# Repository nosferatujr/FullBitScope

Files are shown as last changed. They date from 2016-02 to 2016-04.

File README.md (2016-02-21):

# FullBitScope
Power Controller and 3p Printed box for BitScope Raspberry Pi and Official Touch 7'' Display

full description in : http://nosfebloc.blogspot.com.es/

We plan also sell on line both the assembled pcb and the box, just in case you have difficulties on build yours, but first we need to buid the first working unit.

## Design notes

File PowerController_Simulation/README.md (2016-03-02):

Simulación para proteus
Hex file is only for test propose. For use on your prototipe use the one on the PowerController_PIC folder

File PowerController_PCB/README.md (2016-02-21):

Schematic and PCB created with http://www.cadsoftusa.com/download-eagle/freeware/

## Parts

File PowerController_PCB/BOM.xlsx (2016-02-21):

Part | Value | Device | Package | Description | MF | OC_FARNELL | OC_NEWARK
C1 | 100n | C-EUC0805 | C0805 | CAPACITOR, European symbol
IC1 | 12F629 | PIC12F629SN | SO-08 | Data Sheet 8-Pin FLASH-Based 8-Bit CMOS Microcontrollers | MICROCHIP | 9759000 | 61K3433
JP1 | USB-RECEPTABLE | USB-RECEPTABLE | FCI-10103594-0001LF | USB Receptable |  | 2293752(farnell) (http://es.farnell.com/jsp/search/productdetail.jsp?CMP=i-ddd7-00001003&sku=2293752)
Q1, Q2 | AP4435GH | IRFR5305 | D-PAK_TO252AA | HEXFET Power MOSFET
R1, R3, R4, R7 | 2k2 | R-EU_R0805 | R0805 | RESISTOR, European symbol
R2 | 330 OHMIOS | R-EU_R0805 | R0805 | RESISTOR, European symbol
R5, R6 | 4k7 | R-EU_R0805 | R0805 | RESISTOR, European symbol
S1 | RF15L2 | RF15L2 | RF15L2 | RAFI SWITCH
SV1 |  | MA05-1 | FE05-1 | PINES MACHO |  | unknown | unknown
SV2 |  | MA04-1 | MA04-1 | PINES MACHO ACODADO |  | unknown | unknown
X1, X2 | 22-23-2021 | MA02-1 | 22-23-2021 | PINES MACHO ACODADO | MOLEX | 1462926 | 25C3832
T1, T2, T3 | BC848 | BC848 | SOT23 | NPN TRANSISTOR

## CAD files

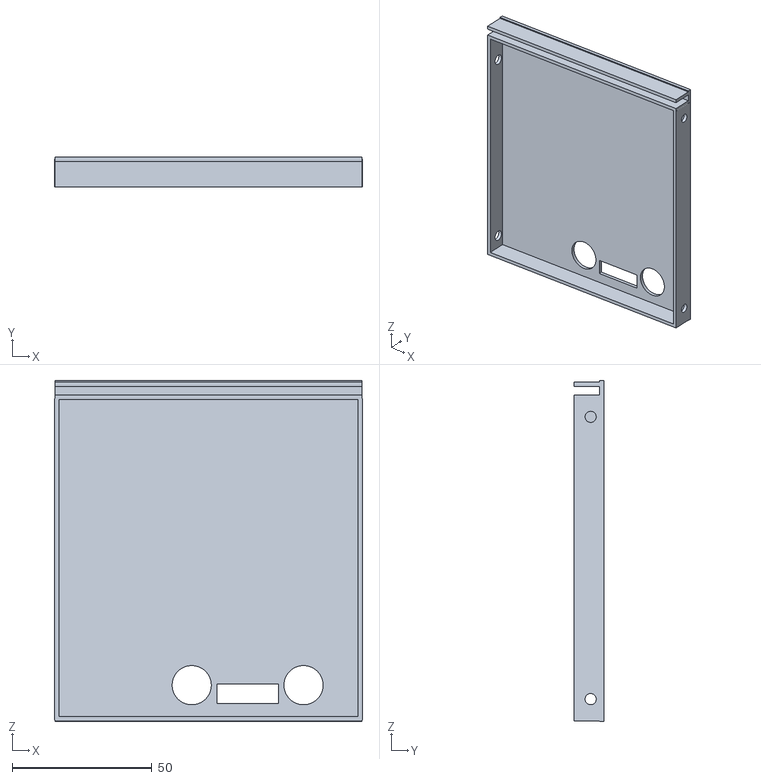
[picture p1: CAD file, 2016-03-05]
Box_STL_files/left.stl
110.2 x 10.8 x 122.0

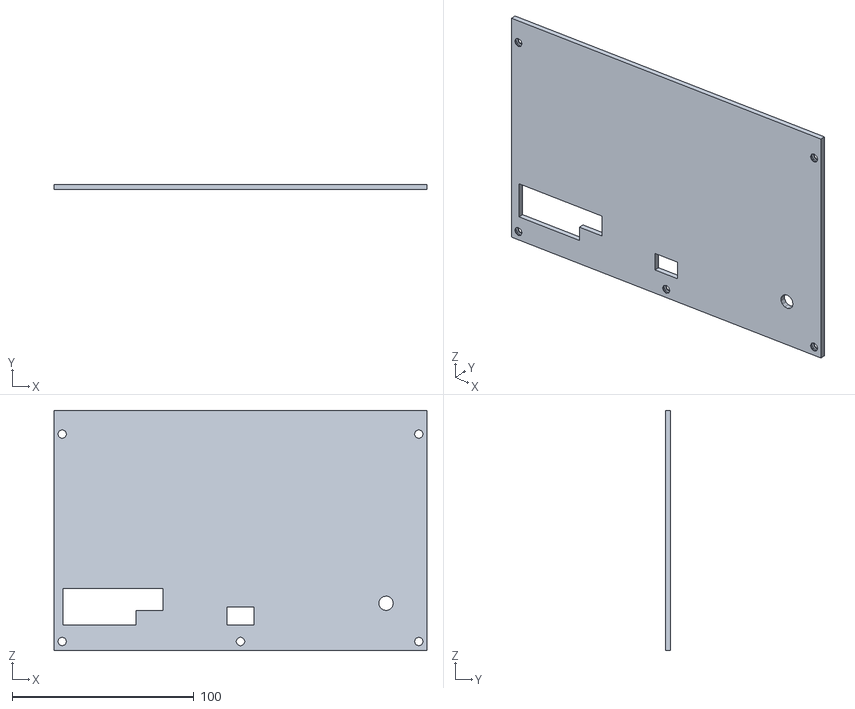
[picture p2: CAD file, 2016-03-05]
Box_STL_files/rear.stl
205.0 x 3.00 x 132.0

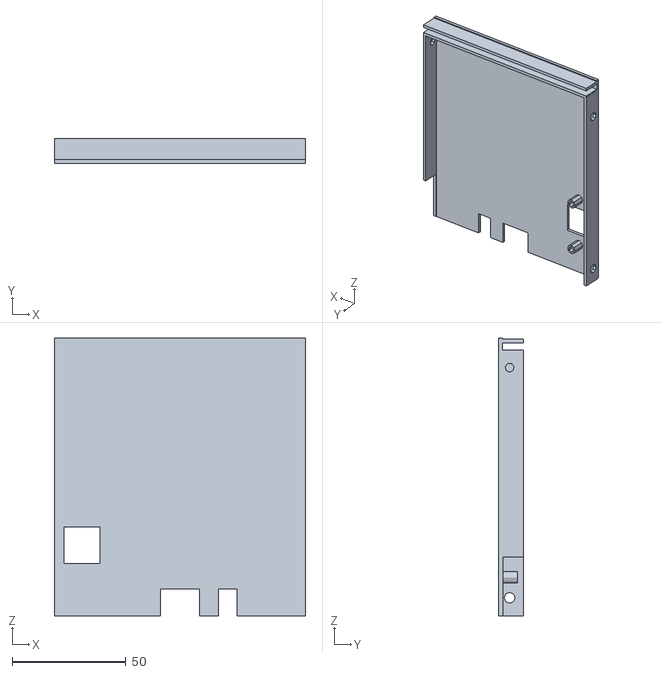
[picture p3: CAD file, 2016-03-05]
Box_STL_files/right.stl
110.2 x 10.8 x 122.0

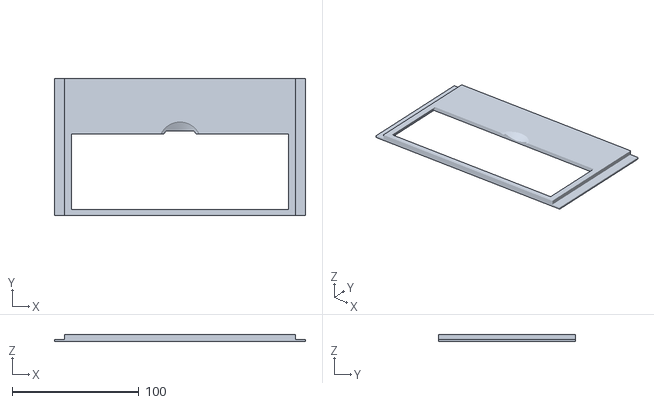
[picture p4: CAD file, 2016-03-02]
Box_STL_files/top1.stl
198.0 x 108.0 x 5.30

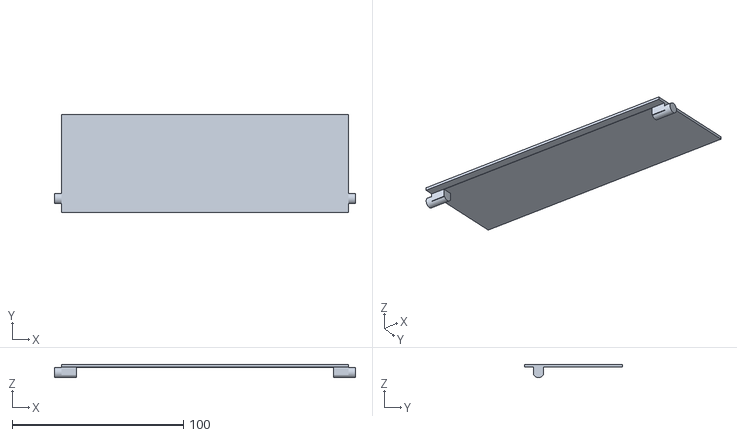
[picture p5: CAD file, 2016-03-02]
Box_STL_files/top3.stl
176.0 x 57.5 x 7.80

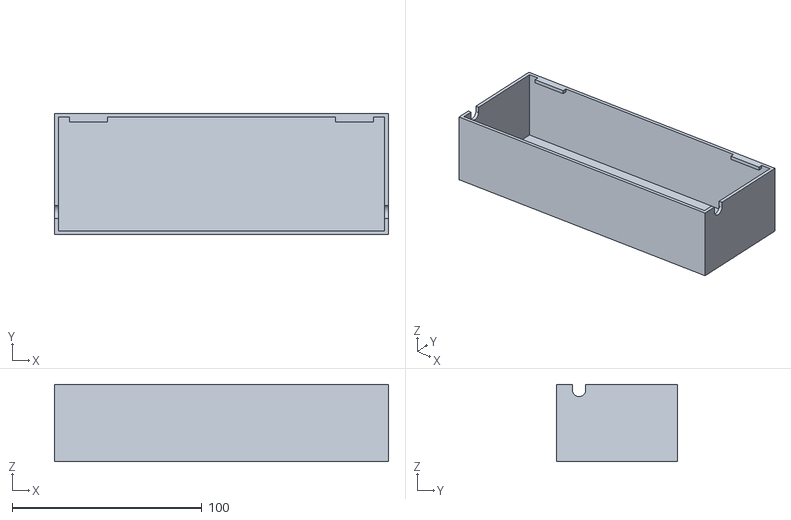
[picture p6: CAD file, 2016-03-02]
Box_STL_files/top2.stl
176.0 x 64.0 x 40.8

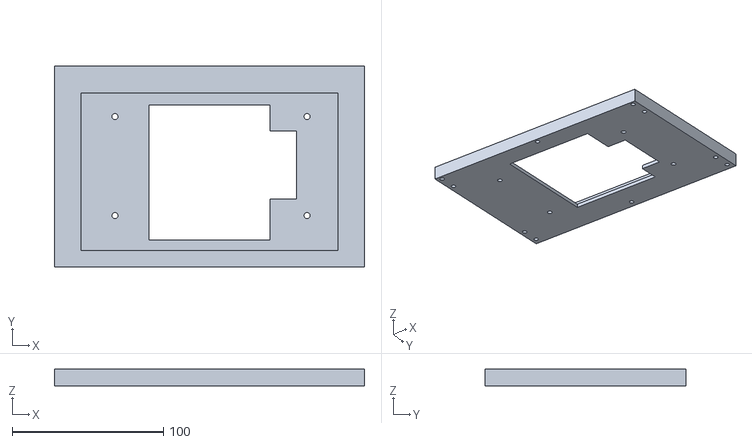
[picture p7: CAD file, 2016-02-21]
Box_STL_files/front.stl
205.0 x 132.9 x 11.0

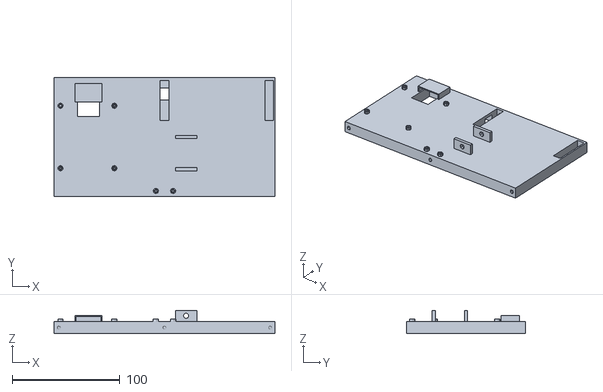
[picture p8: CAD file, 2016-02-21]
Box_STL_files/base.stl
205.0 x 110.0 x 21.5

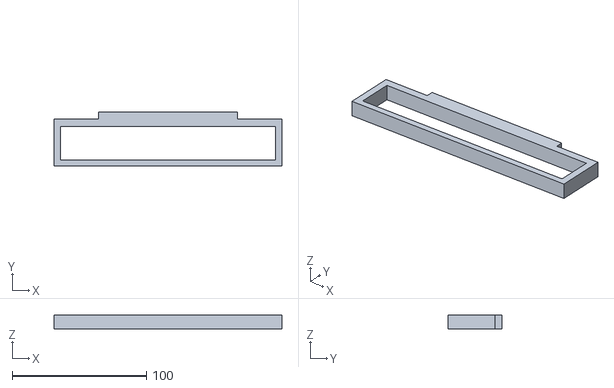
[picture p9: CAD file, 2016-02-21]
Box_STL_files/foot.stl
170.0 x 40.0 x 10.5

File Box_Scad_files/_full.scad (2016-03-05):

include <base.scad>
include <foot.scad>
include <front.scad>
include <top.scad>
include <right.scad>
include <left.scad>
include <rear.scad>

translate([0, -57, 61 ]) rear(); 

color("green")base();
  translate([0, 40, -21 ]) rotate([90, 0, 0 ])
foot();

  translate([0, 60.5, 59.5 ]) rotate([270, 180, 0 ])
front(); 

  translate([-102, 0, 66 ]) rotate([0, 0, 270 ])
color("red")right();

   translate([102, 0, 66 ]) rotate([0, 0, 270 ])
color("red")left();

translate([0, 0 , 125.5 ]) 
 top();

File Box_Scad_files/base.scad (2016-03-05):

module _screws_box(diam){
	translate([98, 0 , 2 ])  cylinder(  9 , 1,  diam/2 ,true);
	translate([0, 0 , 2 ])  cylinder(  9 , 1,  diam/2 ,true);
	translate([-98, 0 , 2 ])  cylinder(  9 , 1,  diam/2 ,true);
} 
 
module screws_box(){
	translate([0, -49, 0 ]) rotate([90, 0 , 0 ]) _screws_box(4);
	translate([0, 49, 0 ]) rotate([-90, 0 , 0 ]) _screws_box(4.5);
} 
module soporte_pi (){
	translate([25, 29, 5.5 ])  cylinder(  5 , 2.5,  2.5 ,true); 
	translate([-25, -29,  5.5 ])  cylinder(  5 , 2.5,  2.5 ,true); 
	translate([-25, 29,  5.5 ])  cylinder(  5 , 2.5,  2.5 ,true); 
	translate([25, -29,  5.5 ])  cylinder(  5 , 2.5,  2.5 ,true); 
}
 module talpwr(){
  translate([8, -50, 4.5 ])  cylinder(  9 , 1,  1.7 ,true);
  translate([-8, -50, 4.5 ])  cylinder(  9 , 1,  1.7 ,true);    
 }
 
 module tal_pi(){
 translate([25, 29, 4.5]) cylinder(  9 , 1,  1.7 ,true);
 translate([-25, -29,  4.5 ]) cylinder(  9 , 1,  1.7 ,true);
 translate([-25, 29,  4.5 ])cylinder(  9 , 1,  1.7 ,true);
 translate([25, -29,  4.5 ]) cylinder(  9 , 1,  1.7 ,true); 
 }

module sd(){
    difference(){
  cube([25 , 17,6 ] ,true ); 
   translate([0, -1,  -1 ])cube([23 , 17, 6 ] ,true );  
    } 
} 
 
module box(){ 
	difference(){
		difference(){
			cube([205 , 110,11 ] ,true ); 
			screws_box();
		}
		translate([(102.5-32)*-1, 33, 0 ])  cube([20 , 28, 12 ] ,true ); 
	}

	translate([-71.5, 0, 0 ]) soporte_pi();
	translate([8, -50, 5.5 ])  cylinder(  5 , 2.5,  2.5 ,true); 
	translate([-8, -50, 5.5 ])  cylinder(  5 , 2.5,  2.5 ,true);  
}
 
 module base(){
	difference(){
		box();
		translate([0, 40, -3 ])   cube([105 , 11,11 ] ,true ); 
		translate([0, -40, -3 ])   cube([105 , 11,11 ] ,true ); 
		translate([97, 34, 1.5 ])   cube([8, 37,9 ] ,true ); 
		translate([0, 34, 1.5 ])   cube([8, 37,9 ] ,true ); 
		translate([-99, 34, 0 ])   cube([8, 37,9 ] ,true ); 
		translate([-71.5, 0, 0 ]) tal_pi();
		talpwr();
	}
	difference(){ 
		union(){ 
			translate([20, 0, 10 ])   cube([20, 3, 12] ,true ); 
			translate([20, -30, 10 ])   cube([20, 3, 12] ,true ); 
		}
		translate([20, -10, 11 ]) rotate([90, 0 , 0 ]) cylinder(  60 , 2.5,  2.5 ,true); 
	}
	translate([-70.5, 41, 8.4 ]) sd();
}
//base();

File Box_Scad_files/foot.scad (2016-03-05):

module foot(){
difference(){
difference(){
translate([0, 0, 0 ])   cube([170 , 40,10.5 ] ,true );
difference(){    
translate([0, 18, 0 ])   cube([175 , 6,12 ] ,true );
translate([0, 18, 0 ])   cube([104 , 6,12 ] ,true );
}
}    
translate([0, -3, 0 ])   cube([160 , 25,12 ] ,true );
}
}

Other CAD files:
PowerController_PIC/production/pipower.X.production.obj
Box_Scad_files/front.scad
Box_Scad_files/left.scad
Box_Scad_files/rear.scad
Box_Scad_files/right.scad
Box_Scad_files/top.scad

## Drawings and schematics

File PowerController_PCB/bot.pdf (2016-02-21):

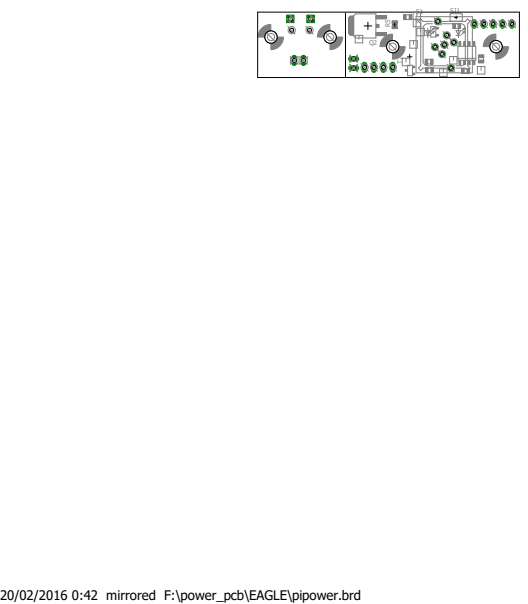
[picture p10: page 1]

20/02/2016 0:42 mirrored F:\power_pcb\EAGLE\pipower.brd

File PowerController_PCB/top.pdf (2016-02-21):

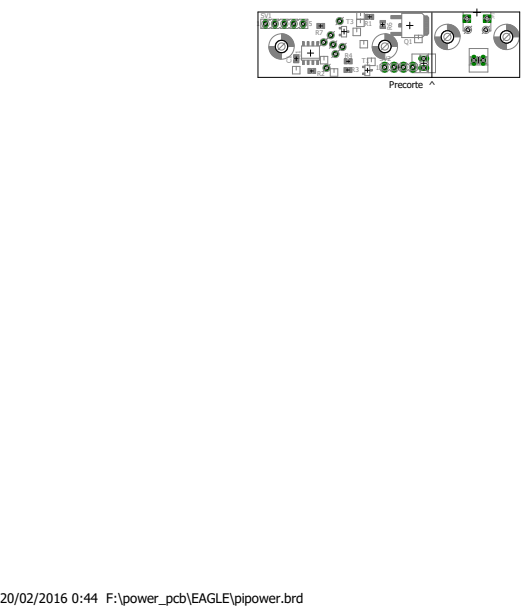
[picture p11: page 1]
JP1 Precorte ^

20/02/2016 0:44 F:\power_pcb\EAGLE\pipower.brd

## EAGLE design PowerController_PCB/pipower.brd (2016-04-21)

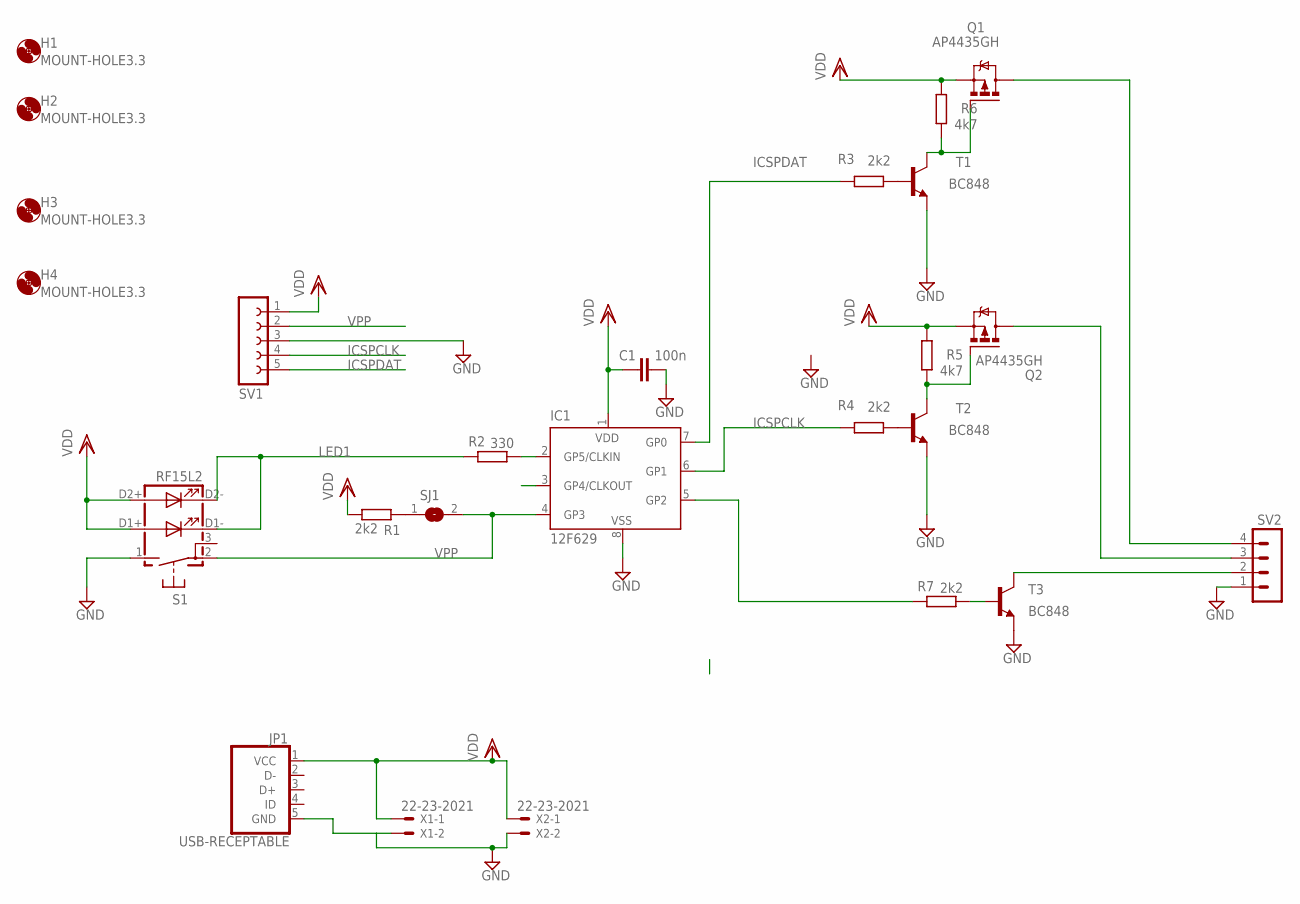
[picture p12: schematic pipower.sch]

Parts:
C1: 100n; C0805
H1, H2, H3, H4: MOUNT-HOLE3.3; 3,3
IC1: 12F629; SO-08; MPN PIC12F629-I/SN
JP1: USB-RECEPTABLE; FCI-10103594-0001LF
Q1, Q2: AP4435GH; D-PAK_TO252AA
R1, R3, R4, R7: 2k2; R0805
R2: 330; R0805
R5, R6: 4k7; R0805
S1: RF15L2
SJ1: SJ
SV1: FE05-1
SV2: MA04-1
T1, T2, T3: BC848; SOT23
X1, X2: 22-23-2021

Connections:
GND: C1.2, IC1.8 (VSS), JP1.5 (GND), S1.1 (S), SV1.3, SV2.1, T1.2 (E), T2.2 (E), T3.2 (E), X1.2, X2.2
ICSPCLK: IC1.6 (GP1), R4.2, SV1.4
ICSPDAT: IC1.7 (GP0), R3.2, SV1.5
LED1: R2.2, S1.D1- (C1), S1.D2- (C2)
unnamed: IC1.5 (GP2), R7.2
unnamed: Q1.4 (D), SV2.4
unnamed: Q2.1 (G), R5.1, T2.3 (C)
unnamed: R3.1, T1.1 (B)
unnamed: R1.2, SJ1.1
unnamed: R4.1, T2.1 (B)
unnamed: Q2.4 (D), SV2.3
unnamed: Q1.1 (G), R6.1, T1.3 (C)
unnamed: IC1.2 (GP5/CLKIN), R2.1
unnamed: SV2.2, T3.3 (C)
unnamed: R7.1, T3.1 (B)
VDD: C1.1, IC1.1 (VDD), JP1.1 (VCC), Q1.3 (S), Q2.3 (S), R1.1, R5.2, R6.2, S1.D1+ (A1), S1.D2+ (A2), SV1.1, X1.1, X2.1
VPP: IC1.4 (GP3), S1.2, SJ1.2, SV1.2

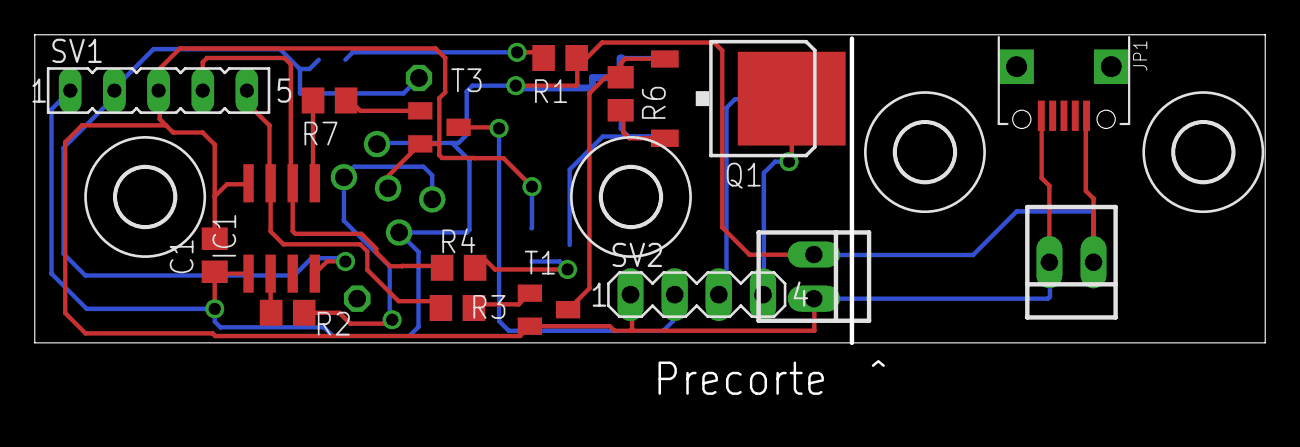
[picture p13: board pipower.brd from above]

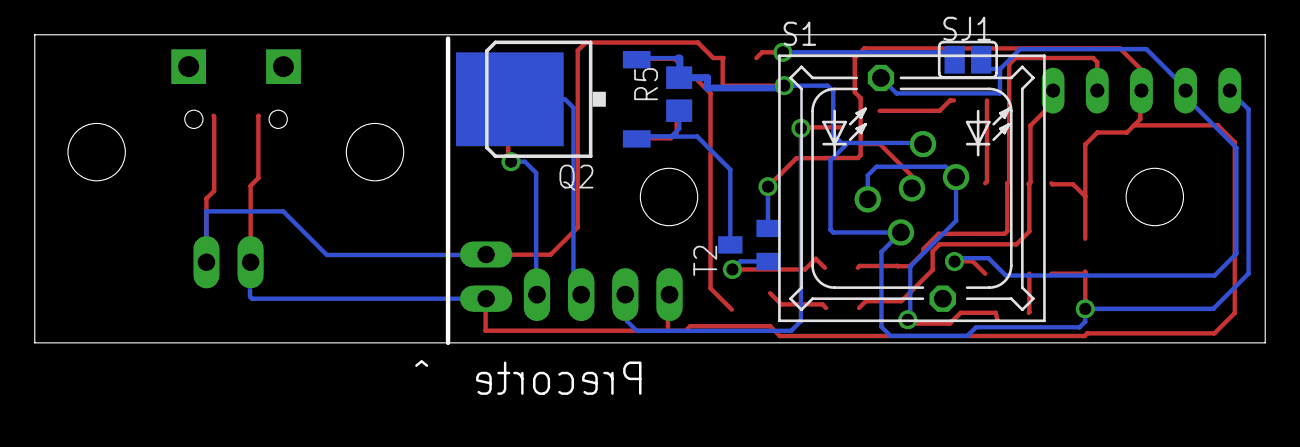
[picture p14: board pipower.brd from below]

Board: 2 copper layers, 70.8 x 17.7 mm, 25 parts (5 on the bottom side), 17 nets.

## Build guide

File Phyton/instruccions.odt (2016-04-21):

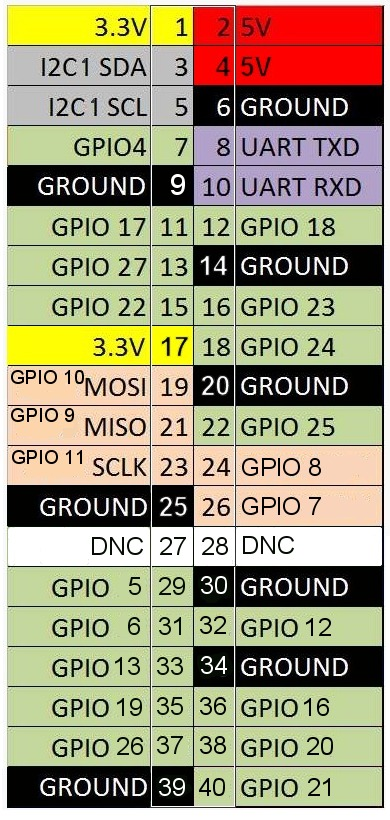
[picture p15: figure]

Com farem servir tambe el codi per HiFiBerry DAC+, Digi+ and Amp+ que ocupa I2c, y tambe els GPIO del 18 al 21, mirarem de fer servir el GPIO 21, que es facil de identificar.

apt-get update

apt-get install gcc python-dev python-pip i2c-tools libi2c-dev python-smbus

pip install RPi.GPIO

mv bye.py.off_button.py

mv bye.py.off_button.py

sudo nano /etc/rc.local

before exit 0; add python /home/pi/.off_button.py

Now when you connect the GPIO pin to ground you should see immediately that the green LED starts flashing and after a few seconds it will flash 10 times, signalling a safe shutdown. Now you can remove the power supply.

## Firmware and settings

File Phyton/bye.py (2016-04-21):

#!/bin/python
#This script was authored by AndrewH7 and belongs to him (www.instructables.com/member/AndrewH7)
#You have permission to modify and use this script only for your own personal usage
#You do not have permission to redistribute this script as your own work
#Use this script at your own risk

import RPi.GPIO as GPIO
import os

gpio_pin_number=21

GPIO.setmode(GPIO.BCM)

GPIO.setup(gpio_pin_number, GPIO.IN, pull_up_down=GPIO.PUD_UP)
#It's very important the pin is an input to avoid short-circuits
#The pull-up resistor means the pin is high by default

try:
    GPIO.wait_for_edge(gpio_pin_number, GPIO.FALLING)
    #Use falling edge detection to see if pin is pulled 
    #low to avoid repeated polling
    os.system("sudo shutdown -h now")
    #Send command to system to shutdown
except:
    pass

GPIO.cleanup()
#Revert all GPIO pins to their normal states (i.e. input = safe)

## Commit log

2016-03-02 Files added, the hex is only for test propouses, to use on real prototipes use the one on the folder PowerController_PIC
2016-03-02 top file added
    [top1.stl, top2.stl, top3.stl]
2016-03-05 full box
    [_full.scad, base.scad, foot.scad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]
2016-04-21 Added files via upload
    faltaba una pista
    [pipower.brd, pipower.sch]
2016-04-21 Added files via upload
    Fichero en python e instrucciones de instalacion
2016-04-21 Added files via upload
    Final production files
    [pipower.X.production.obj]
